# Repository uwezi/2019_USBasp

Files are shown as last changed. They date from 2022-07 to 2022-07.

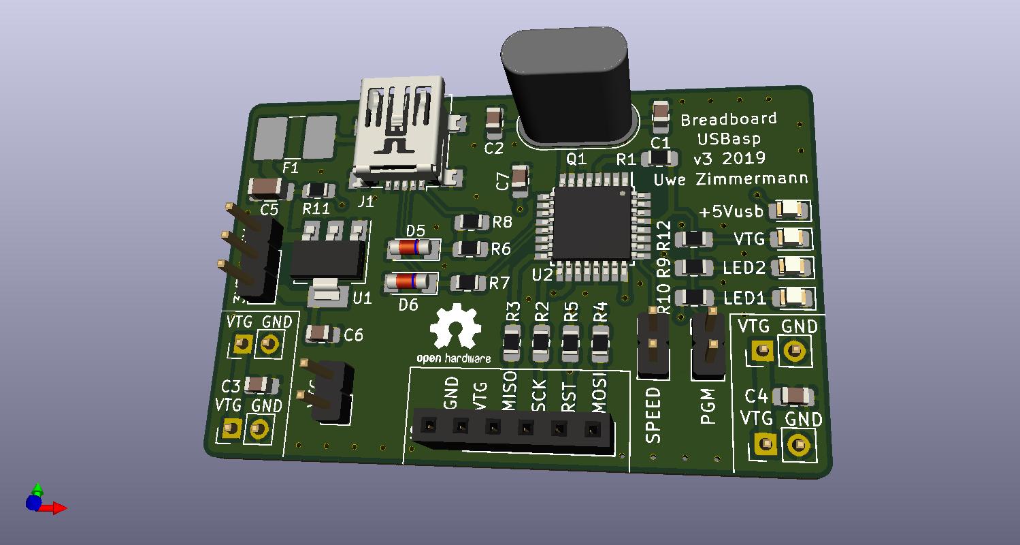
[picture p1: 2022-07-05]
kicad/20190811_usbasp_top.jpg

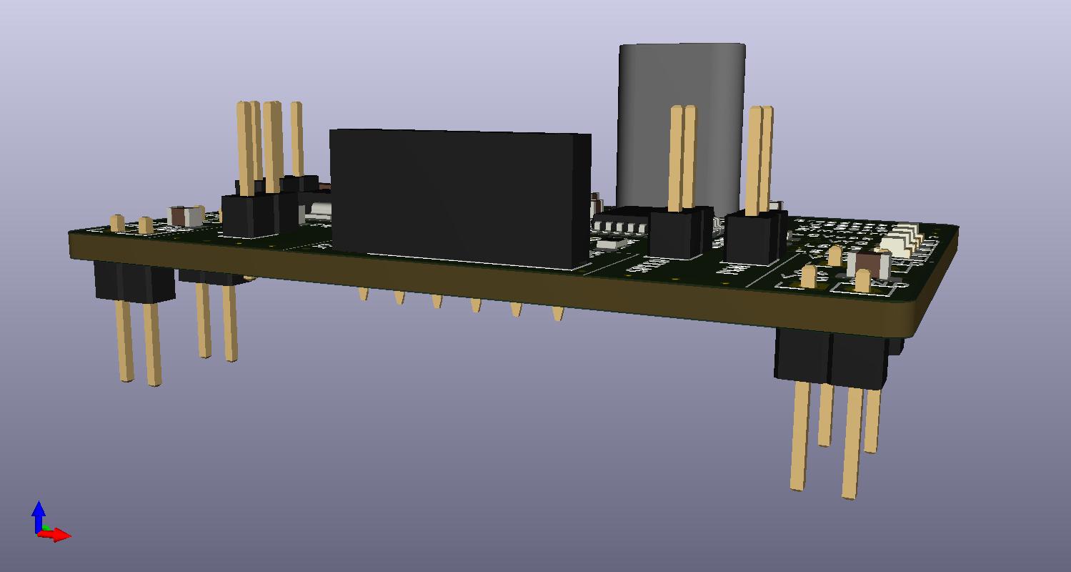
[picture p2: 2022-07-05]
kicad/20190811_usbasp_side.jpg

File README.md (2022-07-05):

# 2019_USBasp
2019 edition of a breadboard USBasp AVR programmer

This is just a quick upload place for my project around an USBasp AVR programmer 
based on the circuit used by Thomas Fischl, but easily placeable on a standard
breadboard.

The necessary gerber files for pcb manufacturing can be found in the folder "production"

A plan could be to merge the hardware layout with another firmware like
https://github.com/mariusgreuel/USBasp

The original firmware from Thomas Fischl can be used
https://www.fischl.de/usbasp/

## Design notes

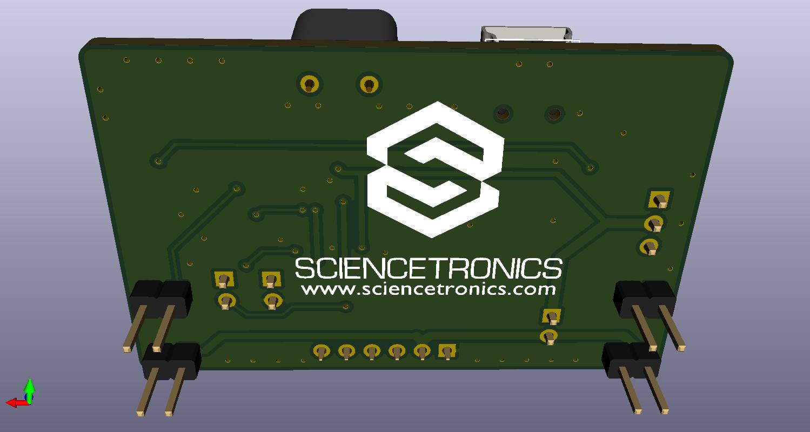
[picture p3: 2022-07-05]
kicad/20190811_usbasp_bot.jpg

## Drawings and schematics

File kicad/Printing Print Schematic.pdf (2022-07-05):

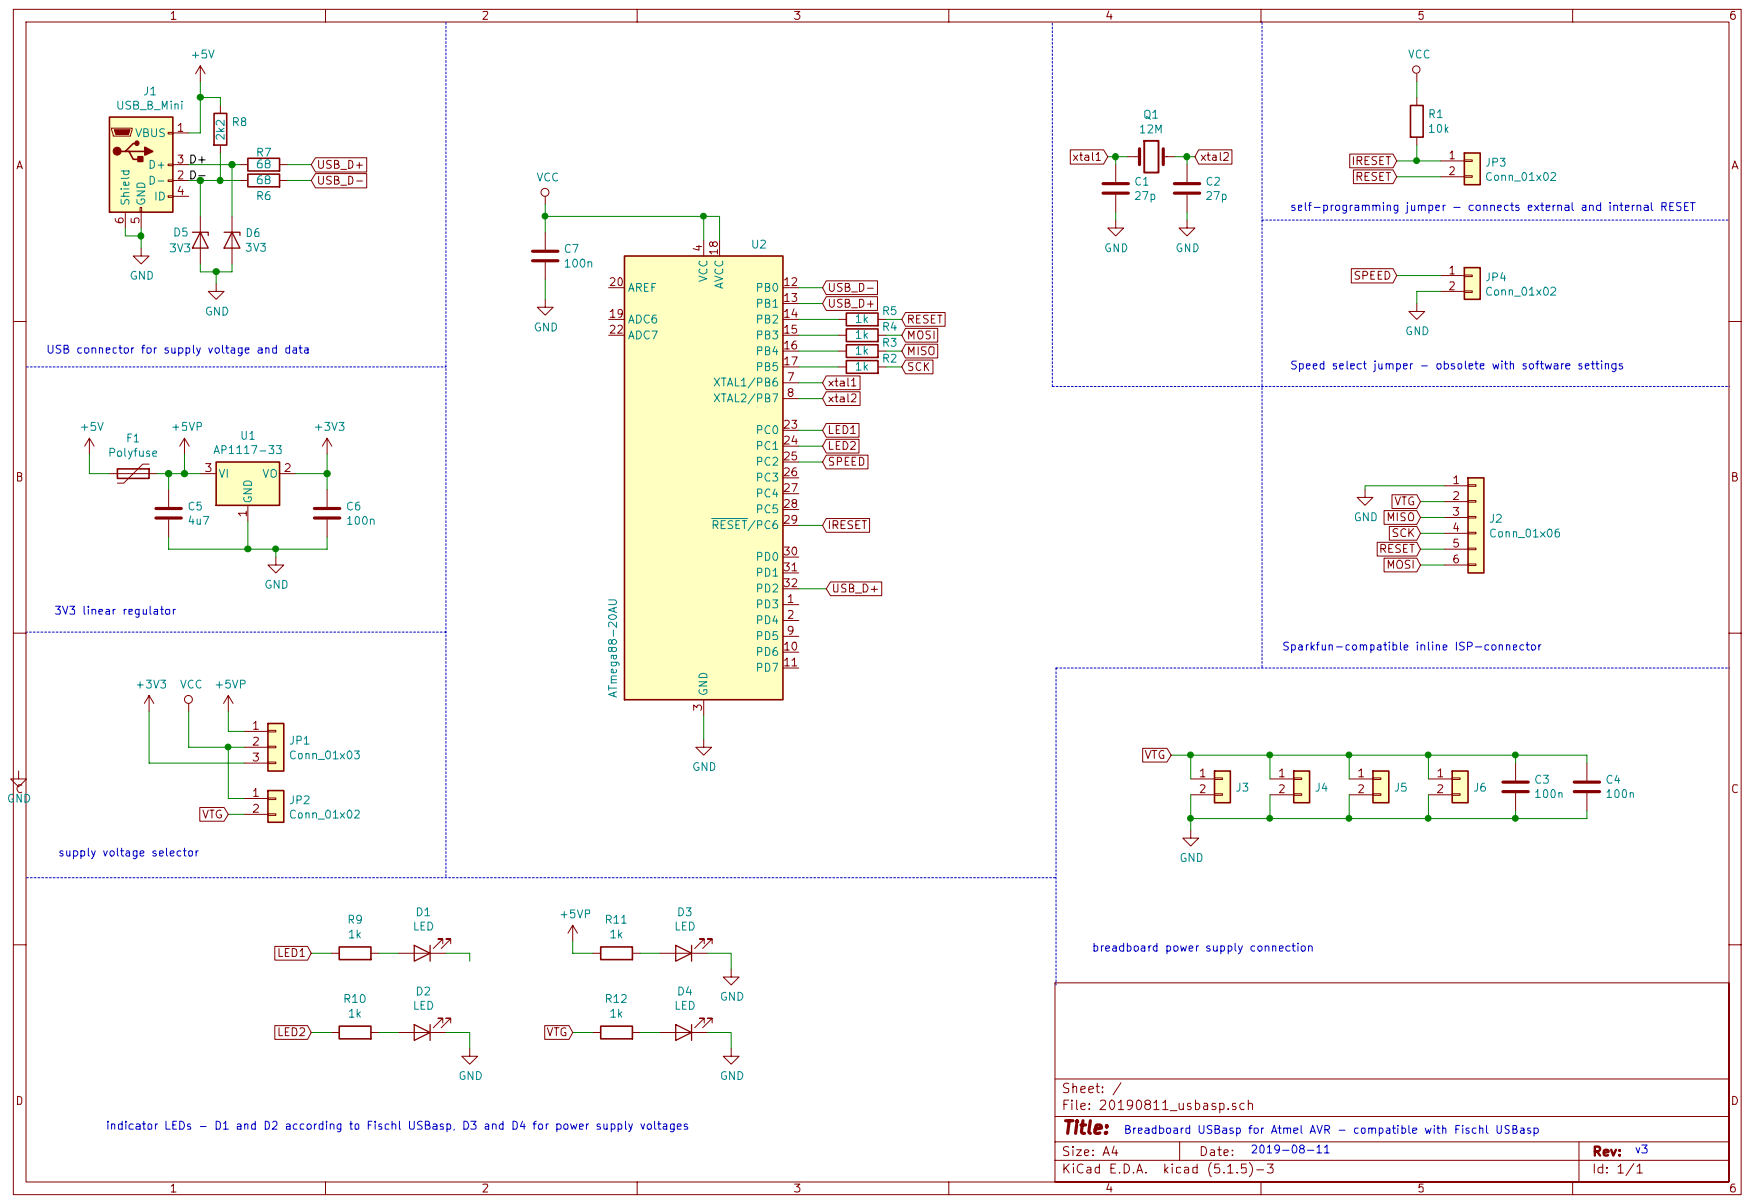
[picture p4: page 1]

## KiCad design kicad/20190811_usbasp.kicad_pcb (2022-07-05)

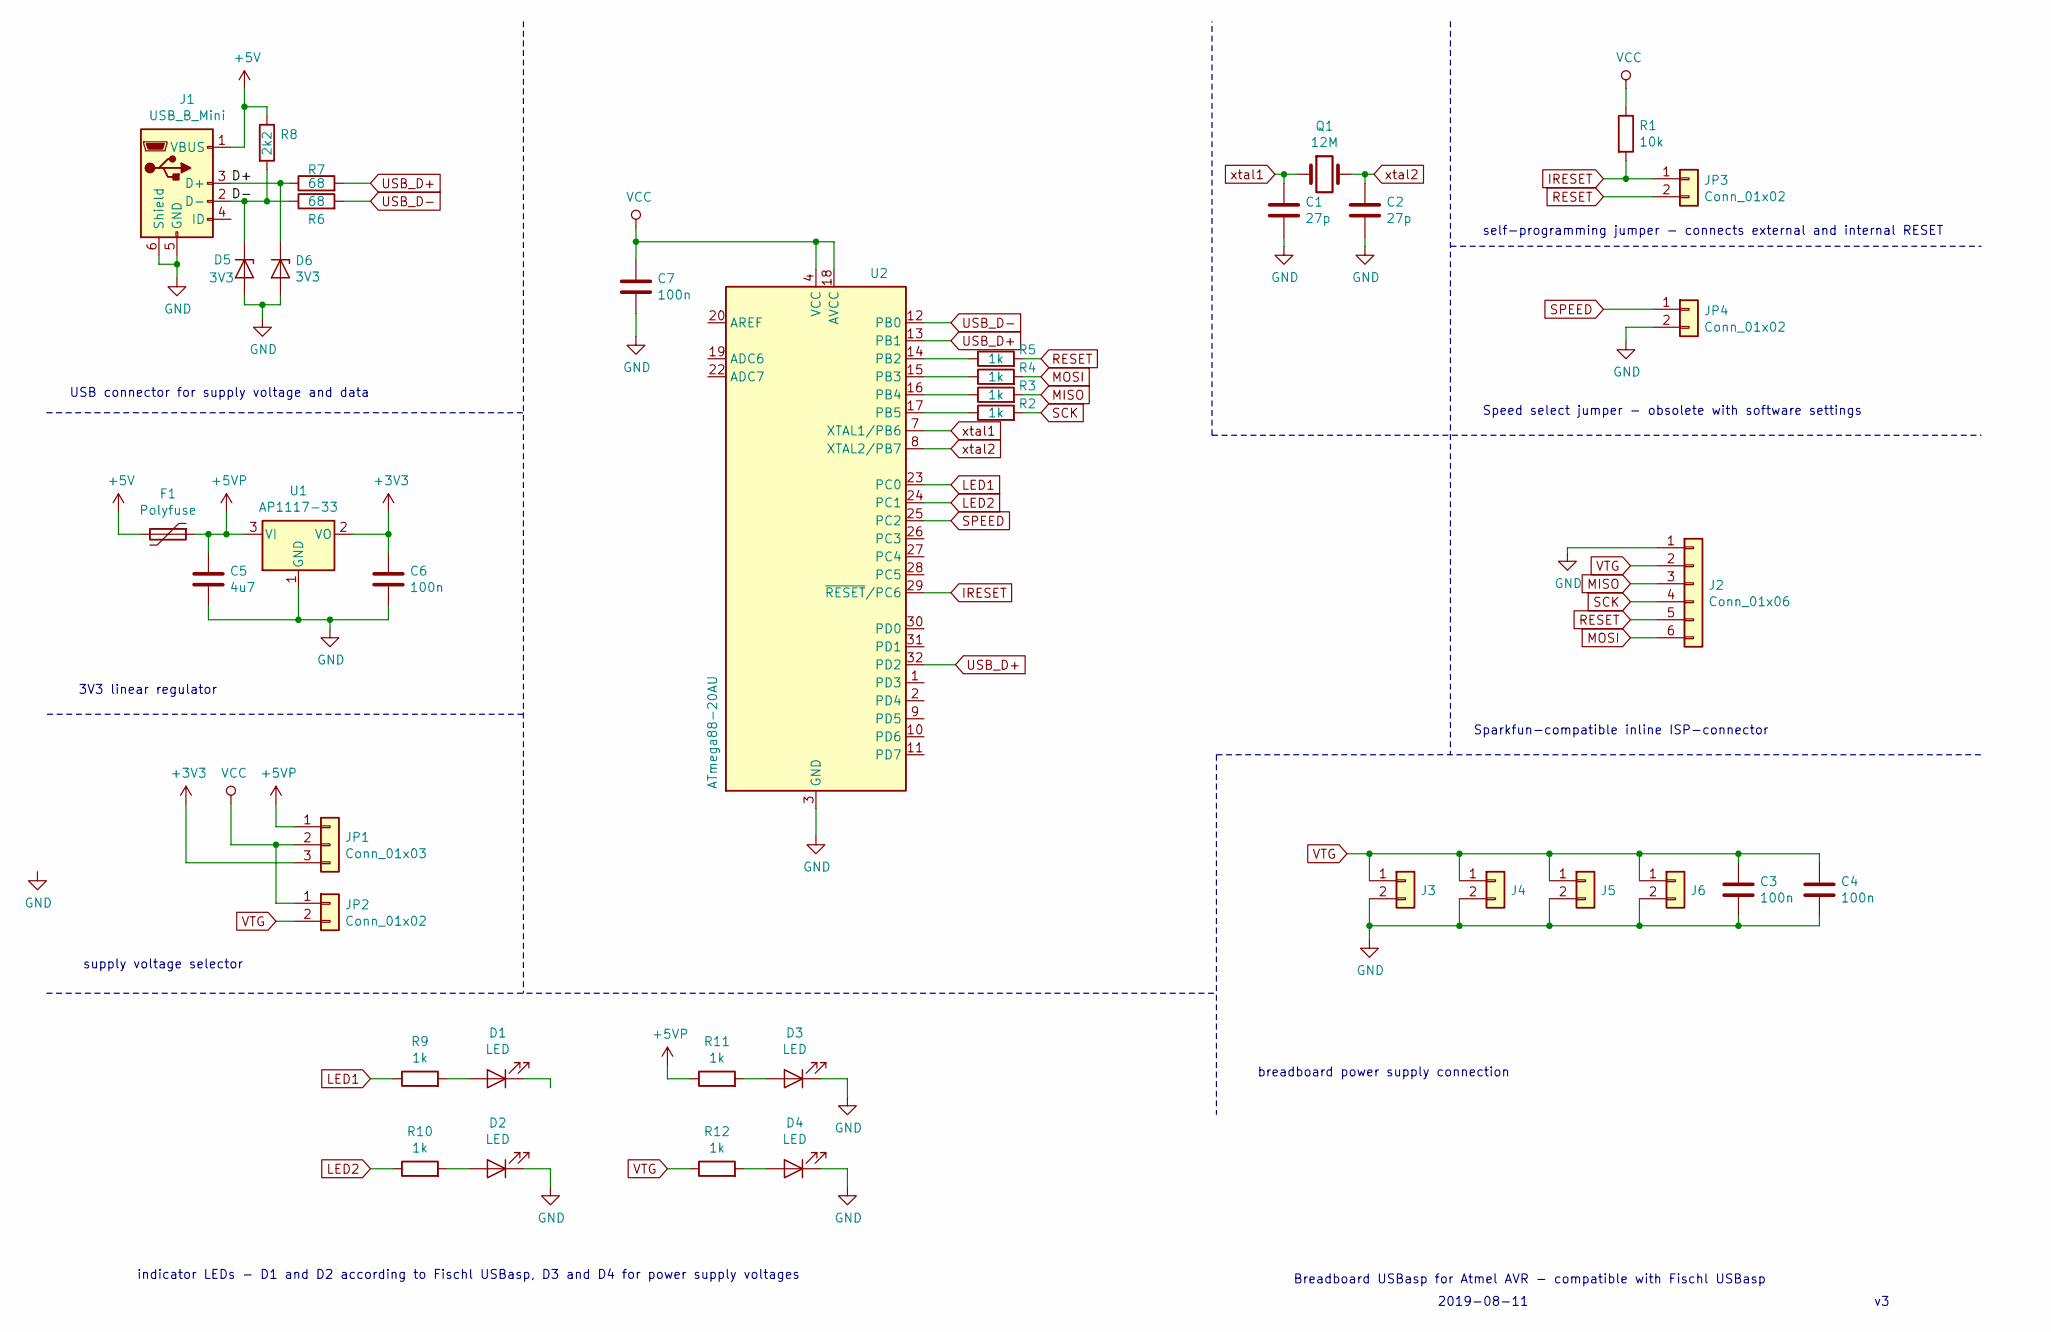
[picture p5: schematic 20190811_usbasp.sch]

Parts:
C1, C2: 27p; C_0805_2012Metric_Pad1.15x1.40mm_HandSolder
C3, C4, C6, C7: 100n; C_0805_2012Metric_Pad1.15x1.40mm_HandSolder
C5: 4u7; C_1206_3216Metric_Pad1.42x1.75mm_HandSolder
D1, D2, D3, D4: LED; LED_0805_2012Metric_Pad1.15x1.40mm_HandSolder
D5, D6: 3V3; D_MiniMELF
F1: Polyfuse; Fuse_2816_7142Metric
J1: USB_B_Mini; USB_Mini-B_Lumberg_2486_01_Horizontal
J2: Conn_01x06; PinSocket_1x06_P2.54mm_Vertical
J3, J4, J5, J6: Conn_01x02; PinHeader_1x02_P2.54mm_Vertical
JP1: Conn_01x03; PinHeader_1x03_P2.54mm_Vertical
JP2, JP3, JP4: Conn_01x02; PinHeader_1x02_P2.54mm_Vertical
Q1: 12M; Crystal_HC18-U_Vertical
R1: 10k; R_0805_2012Metric_Pad1.15x1.40mm_HandSolder
R2, R3, R4, R5, R9, R10, R11, R12: 1k; R_0805_2012Metric_Pad1.15x1.40mm_HandSolder
R6, R7: 68; R_0805_2012Metric_Pad1.15x1.40mm_HandSolder
R8: 2k2; R_0805_2012Metric_Pad1.15x1.40mm_HandSolder
U1: AP1117-33; SOT-223-3_TabPin2
U2: ATmega88-20AU; TQFP-32_7x7mm_P0.8mm

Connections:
+3V3: C6.1, JP1.3, U1.2 (VO)
+5V: F1.2, J1.1 (VBUS), R8.1
+5VP: C5.1, F1.1, JP1.1, R11.1, U1.3 (VI)
/D+: D6.1 (K), J1.3 (D+), R7.1
/D-: D5.1 (K), J1.2 (D-), R6.1, R8.2
GND: C1.2, C2.2, C3.2, C4.2, C5.2, C6.2, C7.2, D1.1 (K), D2.1 (K), D3.1 (K), D4.1 (K), D5.2 (A), D6.2 (A), J1.5 (GND), J1.6 (Shield), J2.1, J3.2, J4.2, J5.2, J6.2, JP4.2, U1.1 (GND), U2.3 (GND), U2.5 (GND), U2.21 (GND)
IRESET: JP3.1, R1.2, U2.29 (~RESET~/PC6)
LED1: R9.1, U2.23 (PC0)
LED2: R10.1, U2.24 (PC1)
MISO: J2.3, R3.2
MOSI: J2.6, R4.2
unnamed: D1.2 (A), R9.2
unnamed: D2.2 (A), R10.2
unnamed: D3.2 (A), R11.2
unnamed: D4.2 (A), R12.2
unnamed: R2.1, U2.17 (PB5)
unnamed: R3.1, U2.16 (PB4)
unnamed: R4.1, U2.15 (PB3)
unnamed: R5.1, U2.14 (PB2)
RESET: J2.5, JP3.2, R5.2
SCK: J2.4, R2.2
SPEED: JP4.1, U2.25 (PC2)
USB_D+: R7.2, U2.13 (PB1), U2.32 (PD2)
USB_D-: R6.2, U2.12 (PB0)
VCC: C7.1, JP1.2, JP2.1, R1.1, U2.4 (VCC), U2.6 (VCC), U2.18 (AVCC)
VTG: C3.1, C4.1, J2.2, J3.1, J4.1, J5.1, J6.1, JP2.2, R12.1
xtal1: C1.1, Q1.1, U2.7 (XTAL1/PB6)
xtal2: C2.1, Q1.2, U2.8 (XTAL2/PB7)

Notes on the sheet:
Speed select jumper - obsolete with software settings
self-programming jumper - connects external and internal RESET
Sparkfun-compatible inline ISP-connector
breadboard power supply connection
indicator LEDs - D1 and D2 according to Fischl USBasp, D3 and D4 for power supply voltages
supply voltage selector
3V3 linear regulator
USB connector for supply voltage and data
2019-08-11
Breadboard USBasp for Atmel AVR - compatible with Fischl USBasp

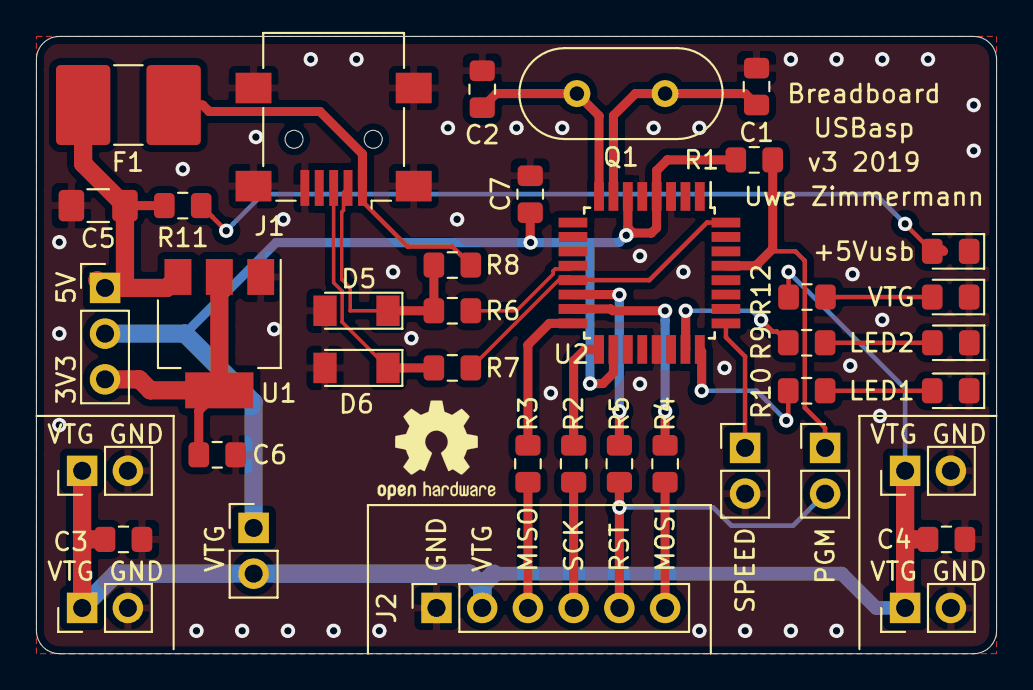
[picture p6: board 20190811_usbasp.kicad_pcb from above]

Board: 2 copper layers, 53.3 x 34.3 mm, 39 parts (0 on the bottom side), 28 nets.

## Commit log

2022-07-05 Add files via upload
    kicad files
    [20190811_usbasp-B_Cu.gbr, 20190811_usbasp-B_Mask.gbr, 20190811_usbasp-B_Paste.gbr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]
2022-07-05 Add files via upload
    ZIP archive with the Gerber files for production
